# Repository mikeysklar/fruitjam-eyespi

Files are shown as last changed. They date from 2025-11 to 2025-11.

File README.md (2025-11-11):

# Fruit Jam → EyeSPI Display Adapter

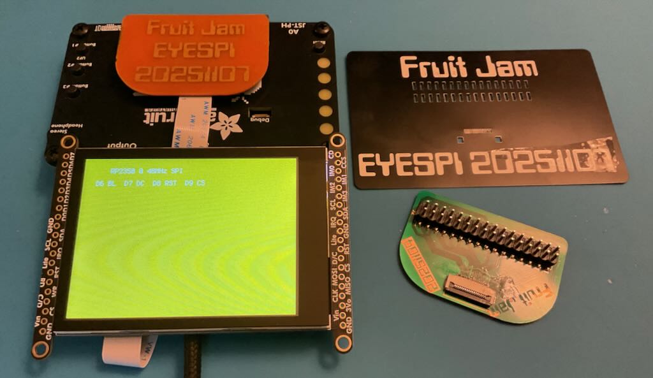
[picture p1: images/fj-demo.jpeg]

*Single-sided PCB CNC-milled, fiber-laser etched, and resin-coated.*

---

## Overview

This project is a **compact breakout PCB** that connects the **16-pin Adafruit Fruit Jam header** to an **18-pin EyeSPI FPC** connector for driving TFT displays 

It allows the **Fruit Jam** to output to Adafruit EyeSPI displays, enabling small embedded builds like:

- 🎧 **MP3 or media players**
- 🕹️ **Mini gaming consoles**
- 💻 **Pocket computers**
- 🔧 **Control panels and dashboards**
- 📟 **Status monitors**
- 🧩 **Rapid prototyping setups**

---

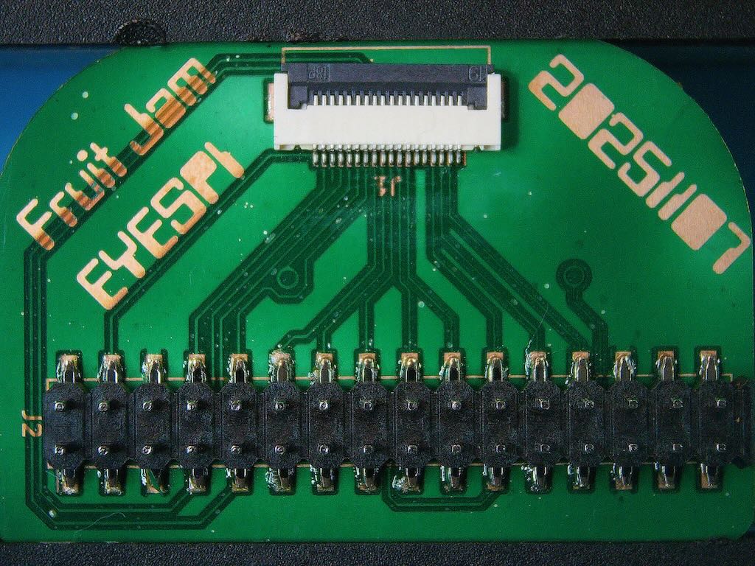
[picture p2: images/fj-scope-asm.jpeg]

*Assembeld finished DIY PCB*

## Features

- Plug-and-play with **Adafruit EyeSPI TFT displays**
- Fabricated as a **single-sided PCB** using **CNC + fiber laser**
- Protected with a **UV resin coat** for strength and finish
- Low Profile and easy SMT stencil assembly

---

## 📁 Repository Structure

| Folder | Description |
|:---|:---|
| [/fj-eyespi/](fj-eyespi) | KiCad schematic and PCB layout files |
| [/fj-eyespi/fj-eyespi.step](fj-eyespi/fj-eyespi.step) | 3D STEP and render files for case design or visualization |
| [/images/](images) | Build photos, renders, and setup examples |

---

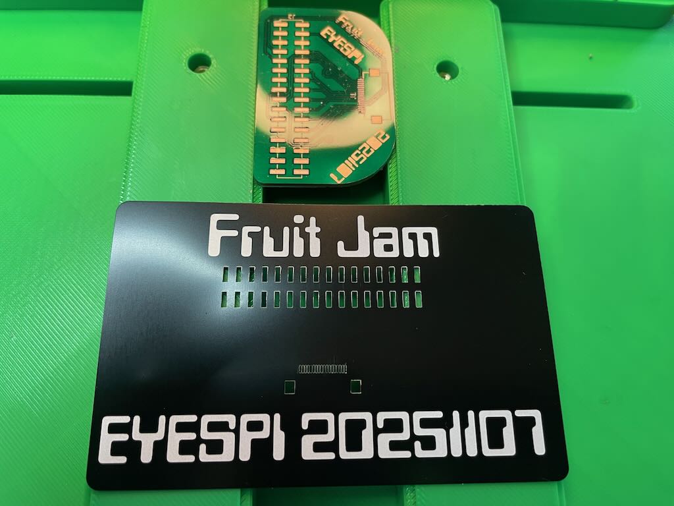
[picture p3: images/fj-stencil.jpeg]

*Metallic Stencil and Home Etched glossy PCB in solder paste jig*

## 🧩 Hardware Design

- **Input:** 16-pin Fruit Jam display header  
- **Output:** 18-pin EyeSPI FFC (0.5 mm pitch)  
- **Board Type:** Single-sided PCB  
- **Fabrication:** CNC milled + laser etched traces + resin coat  
- **Connector Orientation:** FFC faces upward (standard EyeSPI alignment)

### 🧩 Pin Mapping — Fruit Jam 2×16 Header (J2) → EyeSPI 18-Pin Socket (J1)

| Function | Fruit Jam | EyeSPI Pin | Notes |
|:---|:---:|:---:|:---|
| 5 V | 1 / 2 / 31 / 32 | — | 5 V rail (unused) |
| 3.3 V (VCC) | 3 / 30 | 18 (VCC) | Main display power |
| GND | 5 / 6 / 28 / 29 | 16 (GND) | Ground return |
| Backlight | 8 | 17 (lite) | Controls display backlight |
| SCL / SPI CLK | 7 / 21 | 15 (sck) | SPI clock signal |
| SDA / SPI MOSI | 9 / 17 | 14 (mosi) | SPI data (MCU → display) |
| MISO | 19 | 13 (miso) | SPI data (display → MCU) |
| DC (Display Command) | 10 | 12 (dc) | Command / data select |
| RESET | 12 / 25 | 11 (rst) | Hardware reset |
| TCS (Display CS) | 14 | 10 (tcs) | Display chip-select |
| SDCS (SD Card CS) | 16 | 9 (sdcs) | SD card chip-select |
| MCS | 18 | 8 (mcs) | Memory chip-select (optional) |
| TSCS (Touch CS) | 20 | 7 (tscs) | Touch controller chip-select |
| SCL /I²C | 7 | 6 (scl) | touch controller (I²C) |
| SDA /I²C | 9 | 5 (sda) | touch controller (I²C) |
| INT | 22 | 4 (int) | Touch interrupt signal |
| BUSY | 24 | 3 (busy) | ePaper / Touch busy signal |
| GPIO1 | 26 | 2 (gpio1) | General purpose I/O |
| GPIO2 | 27 | 1 (gpio2) | General purpose I/O |

---

### Schematic

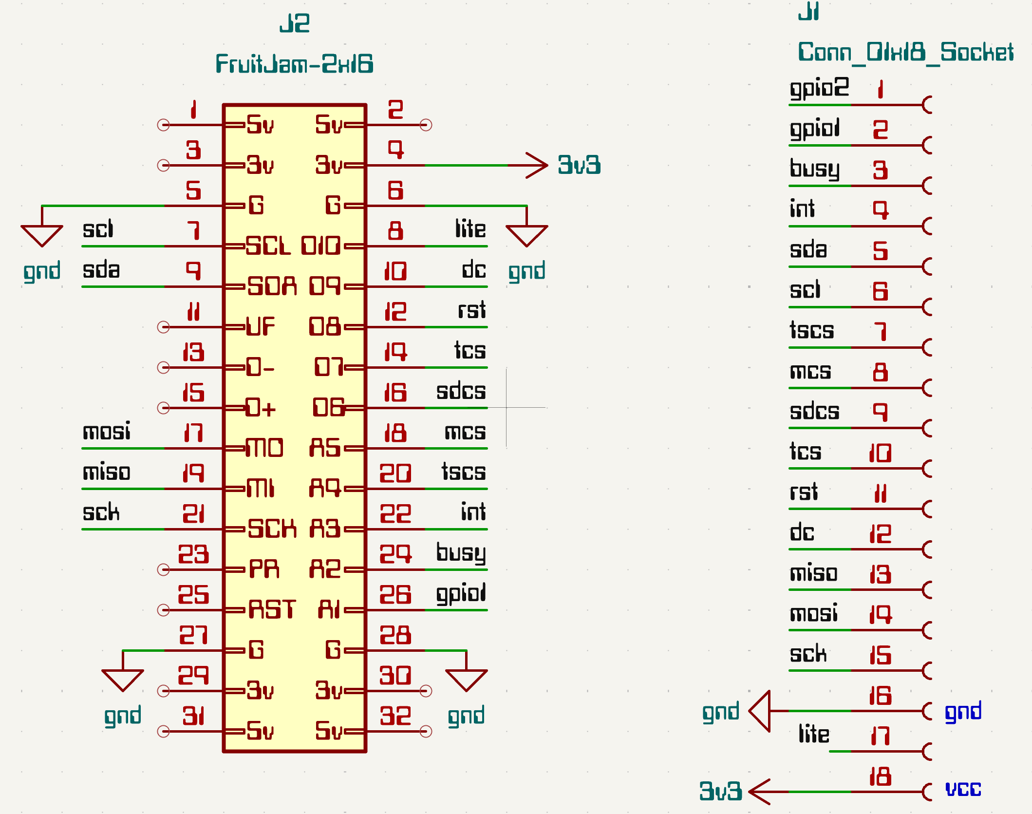
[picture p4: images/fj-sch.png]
KiCAD Schematic


---

### PCB 

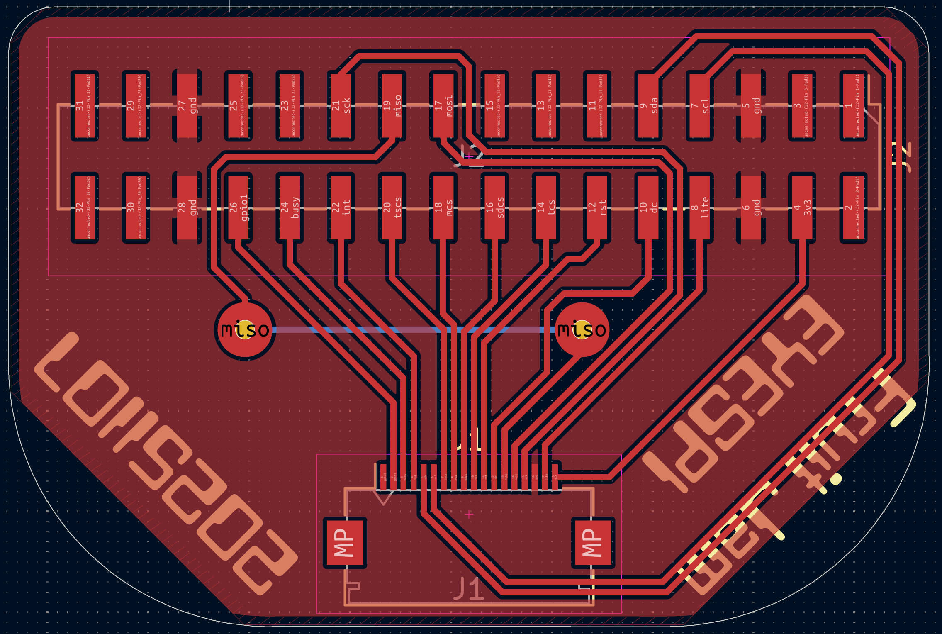
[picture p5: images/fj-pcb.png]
KiCAD PCB


---

### Notes

- Logic-level operation is **3.3 V only** — no level shifting required.  
- Supports SPI or I²C Touch EyeSPI displays (e.g. ST7735, ST7789, ILI9341, GC9A01, etc.).  
- Unused pins can be repurposed for GPIO or future display functions.  

---

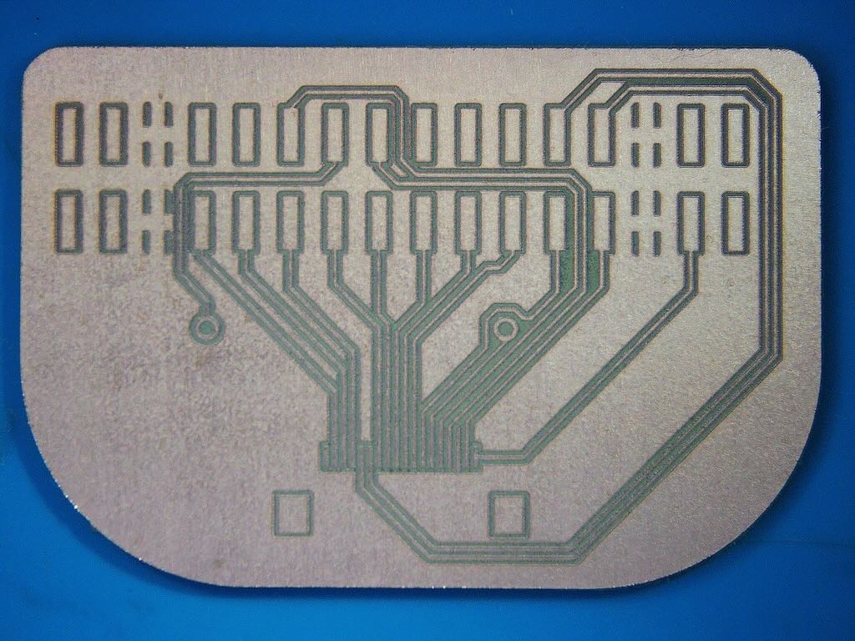
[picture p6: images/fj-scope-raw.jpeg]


## Bill of Materials

The adapter has been validated with the following setup:

| **Category** | **Part** | **Link** |
|---|---|---|
| **Main Board** | Adafruit Fruit Jam (RP2350-based) | [Fruit Jam](https://www.adafruit.com/product/6200) |
| **Display** | 2.8" TFT LCD with Cap Touch | [Adafruit 2.8" TFT LCD with Cap Touch (PID 2090)](https://www.adafruit.com/product/2090) |
| **Flex Cable** | EYESPI Cable - 18 Pin 100mm | [EYESPI Cable - 18 Pin 100mm (PID 5239)](https://www.adafruit.com/product/5239) |
| **FPC Connector** | 18-pin 0.5mm Bottom Mount | [18-pin 0.5mm Bottom Mount FPC Connector (AliExpress)](https://www.aliexpress.us/item/3256806632323296.html) |
| **Male Header** | 2x20 SMT Header Male Double Row Short | [2x20 SMT Header Male Double Row Short (AliExpress)](https://www.aliexpress.us/item/3256803267239198.html) |

## Code

[View fj-eyespi.py on GitHub](https://github.com/mikeysklar/fruitjam-eyespi/blob/main/src/fj-eyespi.py)

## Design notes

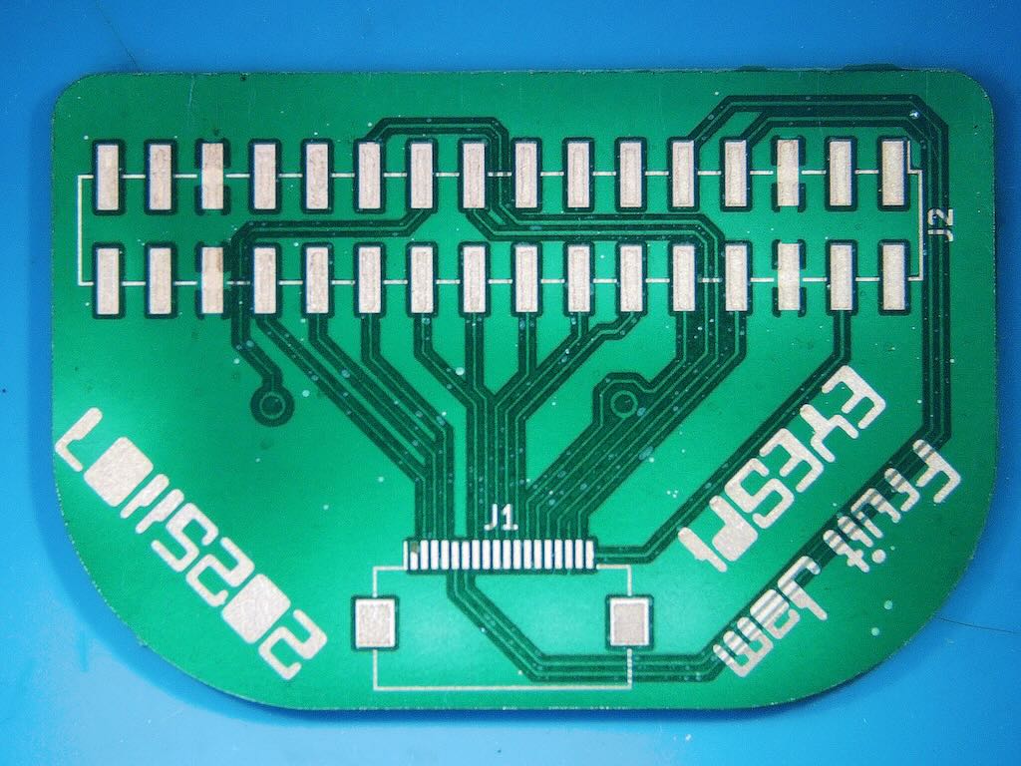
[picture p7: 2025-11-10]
images/fj-scope-glossy.jpeg

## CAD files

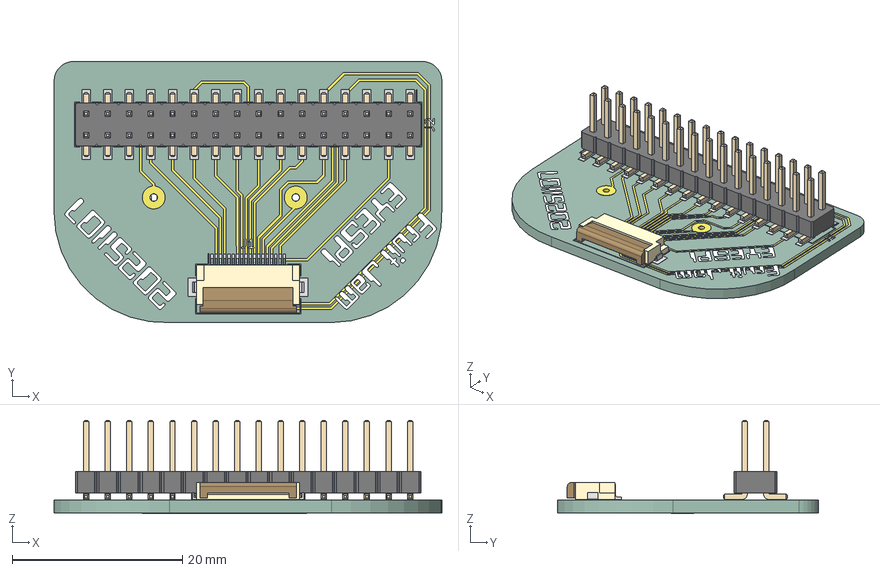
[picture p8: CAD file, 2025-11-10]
fj-eyespi/fj-eyespi.step
45.6 x 30.7 x 11.0 mm
lock
pins
PinHeader_2x16_P2.54mm_Vertical_SMD
fj-eyespi_copper
fj-eyespi_pad
fj-eyespi_via
fj-eyespi_silkscreen
fj-eyespi_PCB

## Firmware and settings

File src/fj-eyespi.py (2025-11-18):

import time
import board
import displayio
import digitalio
import terminalio
from adafruit_display_text import label
from fourwire import FourWire
import adafruit_ili9341

time.sleep(0.5)

# --- release built-in display (Fruit Jam) ---
if hasattr(board, "DISPLAY"):
    board.DISPLAY.auto_refresh = False
displayio.release_displays()

time.sleep(0.5)

# --- your pins ---
tft_backlight = board.D10  # backlight
tft_dc        = board.D9   # D/C
tft_reset     = board.D8   # RST
tft_cs        = board.D7   # CS

# --- backlight on ---
bl = digitalio.DigitalInOut(tft_backlight)
bl.direction = digitalio.Direction.OUTPUT
bl.value = True

# --- SPI bus ---
spi = board.SPI()  # Fruit Jam HW SPI

# --- display bus @ 48 MHz (drop to 40_000_000 if flaky) ---
display_bus = FourWire(
    spi,
    command=tft_dc,
    chip_select=tft_cs,
    reset=tft_reset,
    baudrate=96_000_000,
)

# --- display ---
display = adafruit_ili9341.ILI9341(
    display_bus,
    width=320,
    height=240,
    rotation=0,
)

# --- root group ---
main = displayio.Group()
display.root_group = main

# full-screen bg we can recolor quickly
bg_bitmap = displayio.Bitmap(320, 240, 1)
bg_palette = displayio.Palette(1)
bg_palette[0] = 0x000000
bg = displayio.TileGrid(bg_bitmap, pixel_shader=bg_palette)
main.append(bg)

# text on top so we know pins
text = label.Label(
    terminalio.FONT,
    text="RP2350 @ 48MHz SPI",
    color=0xFFFFFF,
    x=40,
    y=20,
)
main.append(text)

pins = label.Label(
    terminalio.FONT,
    text="D6 BL  D7 DC  D8 RST  D9 CS",
    color=0xFFFFFF,
    x=20,
    y=40,
)
main.append(pins)

# some colors to cycle through
colors = [
    0x000000,  # black
    0xFF0000,  # red
    0x00FF00,  # green
    0x0000FF,  # blue
    0xFFFF00,  # yellow
    0xFF00FF,  # magenta
    0x00FFFF,  # cyan
    0xFFFFFF,  # white
    0x202020,  # dim gray
]

i = 0
while True:
    bg_palette[0] = colors[i]
    i = (i + 1) % len(colors)
    time.sleep(0.5)

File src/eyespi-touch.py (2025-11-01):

import board
import busio
import displayio
import terminalio
import digitalio
from adafruit_display_text import label
from adafruit_display_shapes.circle import Circle

# Import correct FourWire bus class
from fourwire import FourWire

import adafruit_ili9341
import adafruit_focaltouch

# Release any previous displays
displayio.release_displays()

# EyeSPI pin assignments (Fruit Jam bottom header)
spi = board.SPI()
tft_cs = board.A2
tft_dc = board.A1
tft_reset = board.A0
tft_backlight = board.A3

# Setup display bus
display_bus = FourWire(
    spi,
    command=tft_dc,
    chip_select=tft_cs,
    reset=tft_reset,
    baudrate=48_000_000,
)

# Setup display driver
display = adafruit_ili9341.ILI9341(
    display_bus,
    width=320,
    height=240,
    rotation=0
)

# Backlight on
bl = digitalio.DigitalInOut(tft_backlight)
bl.direction = digitalio.Direction.OUTPUT
bl.value = True

# Setup I2C touch
i2c = board.I2C()
touch = adafruit_focaltouch.Adafruit_FocalTouch(i2c, debug=False)

# Build DisplayIO scene
main_group = displayio.Group()
display.root_group = main_group

bitmap = displayio.Bitmap(320, 240, 1)
palette = displayio.Palette(1)
palette[0] = 0x202020
bg = displayio.TileGrid(bitmap, pixel_shader=palette)
main_group.append(bg)

title = label.Label(terminalio.FONT, text="Fruit Jam + ILI9341 + FocalTouch", color=0xFFFFFF, x=10, y=20)
main_group.append(title)

hint = label.Label(terminalio.FONT, text="Touch screen to move circle", color=0xFFFF00, x=10, y=40)
main_group.append(hint)

cursor = Circle(50, 50, 10, outline=0x00FF00)
main_group.append(cursor)

touch_label = label.Label(terminalio.FONT, text="x: --  y: --", color=0xFFFFFF, x=10, y=220)
main_group.append(touch_label)

while True:
    if touch.touched:
        pts = touch.touches
        if pts:
            p = pts[0]
            tx, ty = p["x"], p["y"]
            # Optional axis correction:
            # tx, ty = ty, tx
            # tx = 320 - tx
            # ty = 240 - ty
            cursor.x, cursor.y = tx, ty
            touch_label.text = f"x:{tx:3d} y:{ty:3d}"
    else:
        touch_label.text = "x: --  y: --"

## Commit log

2025-10-10 shrunk, ready to print
    [fj-eyespi-max.kicad_pcb, fj-eyespi-max.kicad_sch, fj-eyespi-min-B_Cu.dxf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]
2025-10-11 silkscreen re-orient
    [fj-eyespi-min-Edge_Cuts.dxf, fj-eyespi-min-F_Cu.dxf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]
2025-11-01 updated connector orientation
    Flipped pin 1 and pin 18 direction by moving tracks for FFC connector
    [fj-eyespi-min.kicad_pcb, fj-eyespi-min.kicad_sch]
2025-11-02 working display
    jumper wired with ada breakout
    | Signal | Pin Name | Function / Purpose |
    | -------------- | -------- | -------------------- |
    | SCK | SCK | SPI Clock |
    | MOSI | MOSI | SPI Data (Host→LCD) |
    | MISO | — | Not used |
    | CS | D9 | Chip Select (TCS) |
    | DC | D7 | Data/Command |
    | RST | D8 | Reset |
    | Backlight (BL) | D6 | LED Backlight Enable |
    | VCC | 3V / 5V | Power Supply |
    | GND | GND | Ground |
    [fj-eyespi-min.kicad_pcb]
2025-11-02 min new layout optimized trax
    [fj-eyespi-min.kicad_sch]
2025-11-04 total remix
    min and max boards re-routed and date, new silks....
    [fj-eyespi-max.kicad_pcb, fj-eyespi-max.kicad_sch, fj-eyespi-min.kicad_pcb]
2025-11-07 re-routing
    still had some flipped pins switching to max only
    [fj-eyespi-max.kicad_pcb, fj-eyespi-max.kicad_sch]
2025-11-08 re-routed max
    aligned with flipped header
    [fj-eyespi-max.kicad_pcb, fj-eyespi-max.kicad_sch]
2025-11-10 updating README, bumped via size up
    [fj-eyespi-min.kicad_pcb, fj-eyespi-min.kicad_sch, fj-eyespi.kicad_pcb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]
2025-11-11 table for BOM added
2025-11-11 sch / pcb images
